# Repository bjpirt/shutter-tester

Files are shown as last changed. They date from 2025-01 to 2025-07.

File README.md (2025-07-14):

# Shutter Tester

A low cost but capable three-point shutter speed tester that runs on ESP32. It uses the PCB design to provide the physical structure of the tester so that all you need to do is solder it together and all of the mechanical design is taken care of.
It runs on ESP32 so is easily updated using the Arduino platform. The project is 100% open source (see the [license file](LICENSE.md) for details).
The UI runs in the browser and communicates with the shutter tester via Bluetooth - you can try out the UI [here](https://bjpirt.github.io/shutter-tester/?demo=true).

## Design

The design of the shutter tester is quite simple; it uses three IS485E / IS486E light sensors with built-in amplifiers to trigger three digital input interrupts on the ESP32 MCU. I wanted to keep the front side of the PCB clear to avoid it ever scratching the camera body so have opted for using surface mount components. I've used quite large packages for these so that they can be more easily hand soldered. The ESP32 uses an "ESP32 C3 Super Mini" module which is very small, can be surface mounted and has USB C built-in which can be used to power the whole board. I've kept the PCB size down to 50mm so that you can take advantage of low cost PCB fabrication. There are silk-screen markings to help position the tester over the camera shutter and three large holes to help see the edges from behind. It should either be taped in place or held with an elastic band.

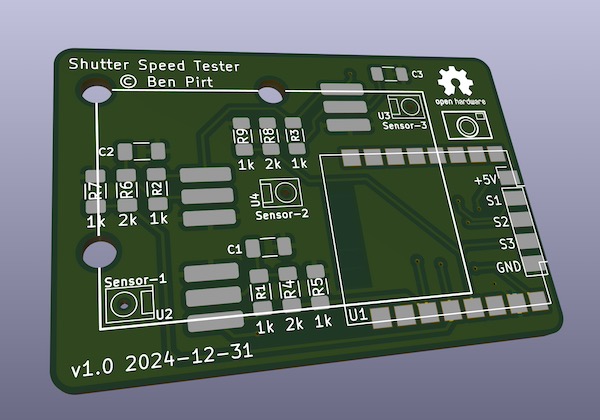
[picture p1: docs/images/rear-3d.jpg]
The shutter tester PCB rear in 3D

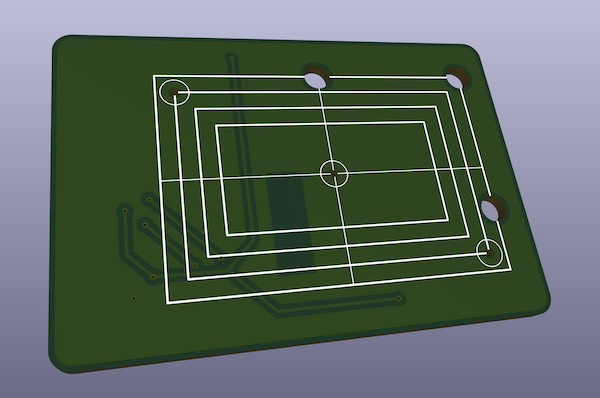
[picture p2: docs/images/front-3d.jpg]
The shutter tester PCB front in 3D

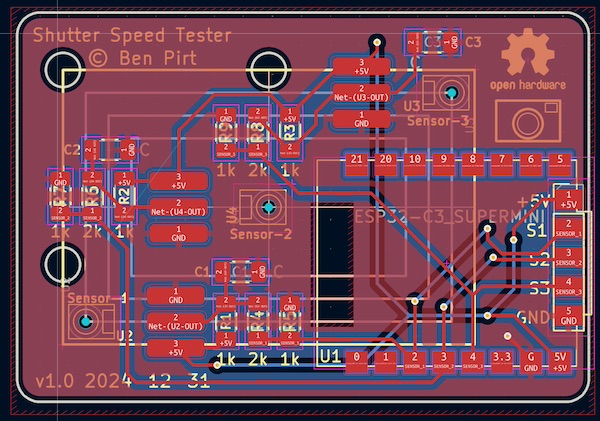
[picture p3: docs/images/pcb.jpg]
The shutter tester PCB


The sensor has a Bluetooth connection and you can connect this to Chrome to use quite a capable web interface so you can get a lot of detail on the calibration. You can try out the UI [here](https://bjpirt.github.io/shutter-tester/?demo=true)

## Bill of materials

The BoM is quite low cost and relatively minimal:

- 1 x ESP32 C3 Super Mini module
- 3 x IS485E light sensor
- 6 x 1k 1206 SMD Resistor
- 3 x 2k 1206 SMD Resistor
- 3 x 0.01uF 1206 SMD Capacitor

## Assembly

The main thing to take care over during assembly is to ensure the lens of the light sensor aligns to the small hole in the PCB that allows the light through. The three legs of the sensor should be bent down slightly so that they can solder onto the three pads on the PCB.

The capacitors and resistors can be easily hand soldered (a finer soldering iron tip helps here) by applying solder to one of the pads on the PCB, using tweezers, solder one end of the component to the soldered pad on the PCB, then solder the other end once it is held in place. If you're experienced in surface mounting you could always use solder paste, but it's pretty straightforward without this. There are markings on the board for which component goes where (C1, C2 and C3 for the capacitors, Resistor values are marked 1k and 2k). The capacitors are optional and may be removed in a future iteration.

It's best to test the ESP32 module before soldering to ensure it's working fine. Program this using the sketch included and make sure it is outputting "Ready to measure" on the serial console (running at 921600 baud).

It's a good idea to place some black insulation tape over the back of the sensors otherwise stray light can cause false readings.

## Usage

Attach the shutter tester behind the shutter of the camera (I normally use 2 - 3 small blobs of Blu-Tak which works well). You can use the three larger holes in the tester to align with the edges of the shutter aperture. Open the shutter once you've this so you can check it's properly positioned by setting the shutter to "Bulb" and opening it. Remove the lens (if possible) and place a strong, even light at the front of the camera. You can use a full size bulb for this so long as it is the type that has a white diffuser bulb, not clear. Basically you want to ensure that light can pass directly through the three holes to reach the sensors, not at an angle. I've also had good results with a small USB powered LED panel.

### Using Bluetooth

There is a user interface that connects to the ESP32 from a Chrome web browser directly and lets you analyse all of the measurements quite easily.

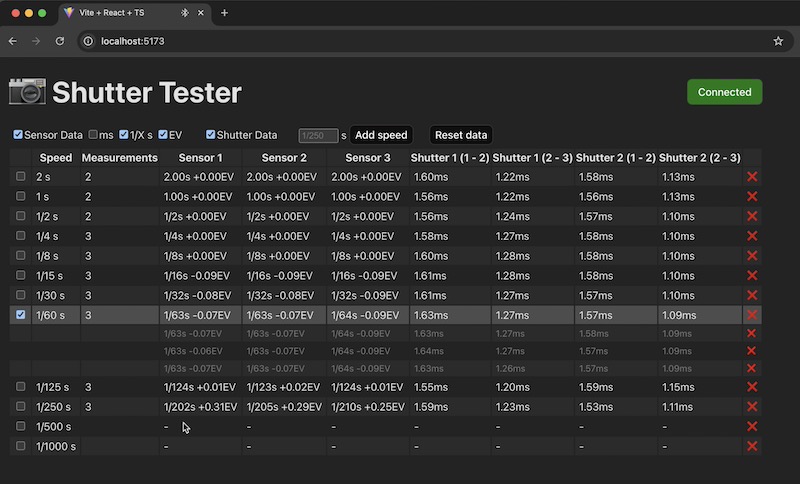
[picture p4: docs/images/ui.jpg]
The Bluetooth user interface


You can easily use the [latest version](https://bjpirt.github.io/shutter-tester/). You should then be able to click the `Connect` button and pair with your shutter tester using Bluetooth. Select the speed you want to test, set up the light and fire the shutter. The new reading should appear in the table.

If you want to just try out the UI without a tester, you can use [this link](https://bjpirt.github.io/shutter-tester/?demo=true) and the "Test" button will simulate a shutter being fired. From a privacy perspective, the UI runs entirely in your browser and nothing goes over the internet.

If you want to run this locally you can do the following:

- Install Node.js (v22)
- Open a terminal in the `ui` folder of this repository
- run `npm install`
- run `npm run dev`
- Go to the URL printed in your terminal ([http://localhost:5173/](http://localhost:5173/))

### Using serial

Open a serial terminal to the ESP32 (this is built in to the Arduino IDE). You'll need to connect at 921600 baud.

Fire the shutter and it will print out the timings to the serial console. There are two sets of timings:

- The time taken for each shutter to travel across the frame - it's important to try and get both shutters moving at around the same speed
- The time each sensor was exposed for in microseconds, milliseconds and fractions of a second

```
Ready to measure

Shutter timing
Shutter 1: 1-2: 16582 uS || 2-3: 12632 uS
Shutter 2: 1-2: 23756 uS || 2-3: 18462 uS

Exposure timing
Sensor 1: 4346 uS || 4.3 mS || 1 / 228
Sensor 2: 5028 uS || 5.0 mS || 1 / 198
Sensor 3: 5528 uS || 5.5 mS || 1 / 182
```

In this example, the time taken for the first shutter to travel between the first and second (centre) sensors was 16582 microseconds and 12632 microseconds between the second (centre) and third sensor. You can see that in this example the second shutter is slow and would need adjusting.

Looking at the exposure time at each sensor, you can see the timings would need adjusting to give a good even exposure. First you would adjust the shutter timings to try and get them similar and then adjust both shutter tensioners to get the exposure time to match the expected (in this case it should have been 1/250 S)

# To Do

- [ ] Calculate variations across shutter and whether they are within tolerances
- [ ] Add graph visualisation of shutter speeds
- [ ] Generate report from three point test
- [x] Enable detailed measurements to be shown / hidden in three point mode
- [x] Deploy to GitHub pages using GitHub actions
- [x] Automatically work out vertical or horizontal shutter
- [x] Display full shutter timing
- [x] Separate shutter timing mode
- [x] Single shot mode (only show last shot timing) - useful for initial tuning
- [x] Compensation for sensor width

## Future

- [ ] Add persistence in the browser to enable common presets to be stored - e.g. camera types with speeds
- [ ] Enable different "runs" to be stored and compared so you can see progression when adjusting
- [ ] Add exposure measurement with light to frequency sensor
- [ ] Investigate reflective measurement from front of camera for e.g. Barnack Leicas
- [ ] Investigate using an analog photodiode instead of a binary sensor

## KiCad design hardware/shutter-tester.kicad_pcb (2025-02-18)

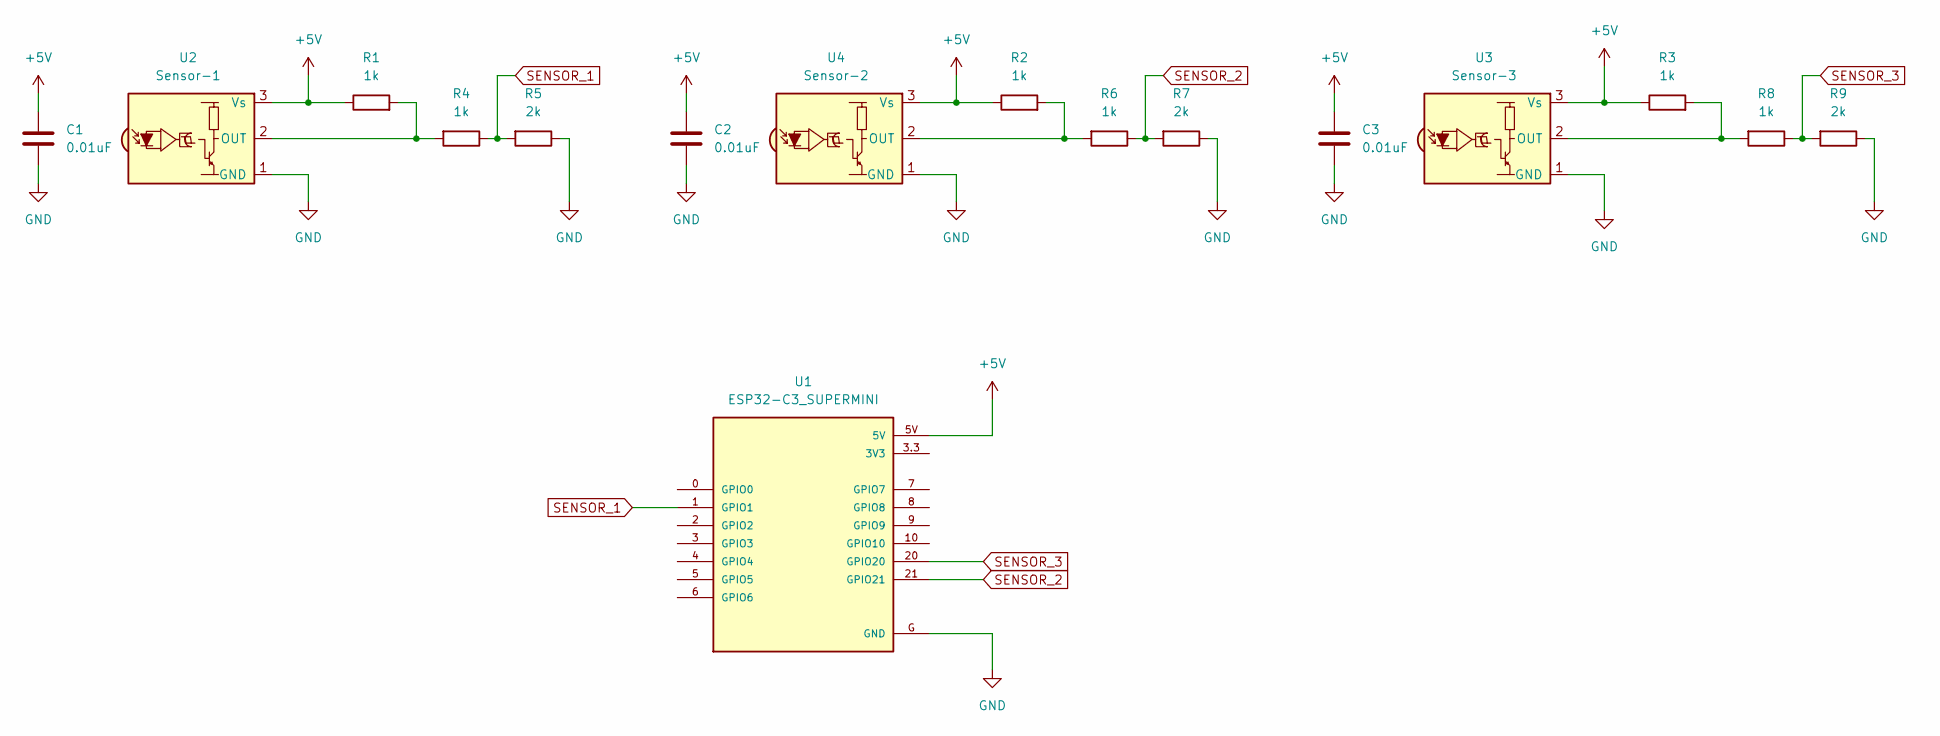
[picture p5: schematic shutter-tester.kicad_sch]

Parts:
C1, C2, C3: 0.01uF; C_1206_3216Metric_Pad1.33x1.80mm_HandSolder
R1, R2, R3, R4, R6, R8: 1k; R_1206_3216Metric_Pad1.30x1.75mm_HandSolder
R5, R7, R9: 2k; R_1206_3216Metric_Pad1.30x1.75mm_HandSolder
U1: ESP32-C3_SUPERMINI; MODULE_ESP32-C3_SUPERMINI_SMT
U2: Sensor-1; Sharp_IS485_Flat_Mount
U3: Sensor-3; Sharp_IS485_Flat_Mount
U4: Sensor-2; Sharp_IS485_Flat_Mount

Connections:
+5V: C1.2, C2.1, C3.2, R1.1, R2.1, R3.1, U1.5V, U2.3 (Vs), U3.3 (Vs), U4.3 (Vs)
GND: C1.1, C2.2, C3.1, R5.1, R7.1, R9.1, U1.G (GND), U2.1 (GND), U3.1 (GND), U4.1 (GND)
unnamed: R1.2, R4.2, U2.2 (OUT)
unnamed: R3.2, R8.2, U3.2 (OUT)
unnamed: R2.2, R6.2, U4.2 (OUT)
SENSOR_1: R4.1, R5.2, U1.1 (GPIO1)
SENSOR_2: R6.1, R7.2, U1.21 (GPIO21)
SENSOR_3: R8.1, R9.2, U1.20 (GPIO20)

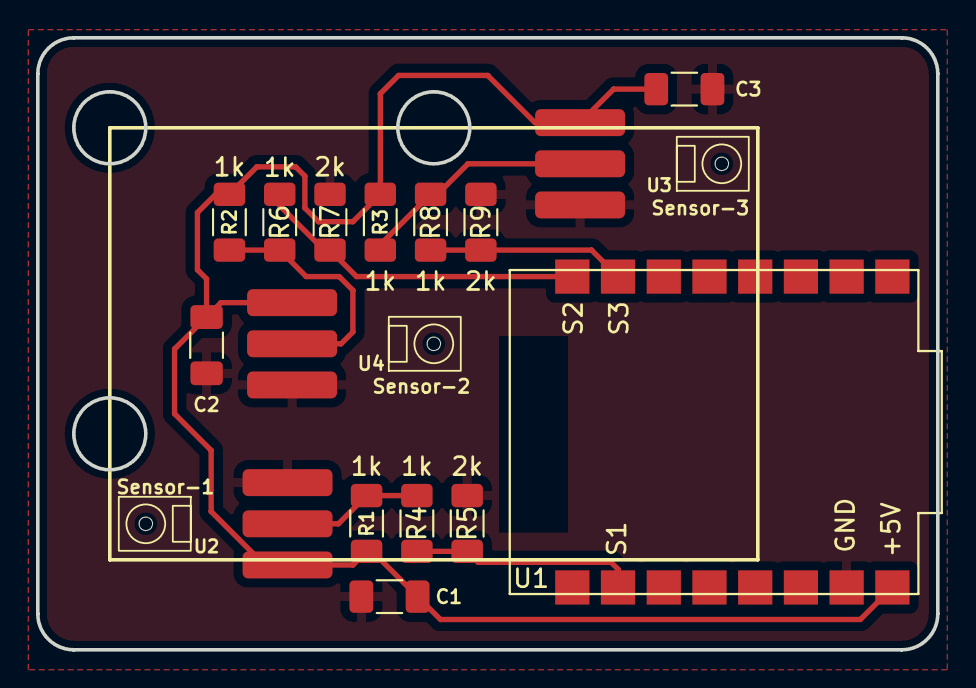
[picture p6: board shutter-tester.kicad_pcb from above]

Board: 2 copper layers, 50.0 x 34.0 mm, 16 parts (0 on the bottom side), 8 nets.

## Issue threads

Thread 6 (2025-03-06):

Seemingly contradictory curtain speed vs exposure

Camacazi, 2025-03-06:
Just wanted to double check that I'm not misunderstanding this correctly in the following screenshot (ignore that outlier entry in the 2nd row).
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

This curtain shutter time appears to imply that the 1st curtain is moving faster than the second (12.79ms vs 13.82 in the 3rd row), but the exposure times across the frame are decreasing, implying the 2nd curtain is running faster.

Am I misinterpreting something? The two seem to be contradicting each other.

Camacazi, 2025-03-06:
Oh okay part of this was my misunderstanding of how the sensors are labelled (1,2,3) vs how the direction of the curtain goes the opposite direction to them (3,2,1).

Closed 2025-03-06.

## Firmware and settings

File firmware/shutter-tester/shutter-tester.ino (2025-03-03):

#define LED 8
#define SENSOR_1 1
#define SENSOR_2 21
#define SENSOR_3 20

#define VERSION "2.2.0"

// #define TEST_BLUETOOTH

#include <BLEDevice.h>
#include <BLEServer.h>
#include <BLEUtils.h>
#include <BLE2902.h>

typedef enum {
  WAIT_FOR_OPEN,
  WAIT_FOR_CLOSE,
  DONE
} sensor_state;

typedef enum {
  THREE_POINT,
  SINGLE_POINT
} sensor_mode;

sensor_state sensor1_state = WAIT_FOR_OPEN;
sensor_state sensor2_state = WAIT_FOR_OPEN;
sensor_state sensor3_state = WAIT_FOR_OPEN;
long sensor1_open_time;
long sensor1_close_time;
long sensor2_open_time;
long sensor2_close_time;
long sensor3_open_time;
long sensor3_close_time;
sensor_mode mode = THREE_POINT;

BLEServer *pServer = NULL;
BLECharacteristic *pSensorCharacteristic = NULL;
BLECharacteristic *pModeCharacteristic = NULL;
bool deviceConnected = false;
bool oldDeviceConnected = false;
char message[128];
long i = 0;

#define SERVICE_UUID "42de79f1-7248-4c9b-9279-96509b8a9f5c"
#define SENSOR_CHARACTERISTIC_UUID "42de79f1-7248-4c9b-9279-96509b8a9f5d"
#define MODE_CHARACTERISTIC_UUID "42de79f1-7248-4c9b-9279-96509b8a9f5e"
#define DEVICE_NAME "ShutterTester"

class MyServerCallbacks : public BLEServerCallbacks {
  void onConnect(BLEServer *pServer) {
    deviceConnected = true;
  };

  void onDisconnect(BLEServer *pServer) {
    deviceConnected = false;
  }
};

class ModeCharacteristicCallbacks : public BLECharacteristicCallbacks {
  void onWrite(BLECharacteristic *pModeCharacteristic) {
    String value = pModeCharacteristic->getValue();
    if (value.length() > 0) {
      int newMode = static_cast<int>(value[0]);
      if (newMode == 1) {
        Serial.print("Setting mode to single point");
        mode = SINGLE_POINT;
      } else if (newMode == 2) {
        Serial.print("Setting mode to three point");
        mode = THREE_POINT;
      }
    }
  }
};

void IRAM_ATTR sensor1_isr() {
  if (!digitalRead(SENSOR_1)) {
    sensor1_open_time = micros();
    sensor1_state = WAIT_FOR_CLOSE;
  } else {
    sensor1_close_time = micros();
    sensor1_state = DONE;
  }
}

void IRAM_ATTR sensor2_isr() {
  if (!digitalRead(SENSOR_2)) {
    sensor2_open_time = micros();
    sensor2_state = WAIT_FOR_CLOSE;
  } else {
    sensor2_close_time = micros();
    sensor2_state = DONE;
  }
}

void IRAM_ATTR sensor3_isr() {
  if (!digitalRead(SENSOR_3)) {
    sensor3_open_time = micros();
    sensor3_state = WAIT_FOR_CLOSE;
  } else {
    sensor3_close_time = micros();
    sensor3_state = DONE;
  }
}

void print_shutter_timing(long t1, long t2, long t3) {
  long s1t1 = t2 - t1;
  long s1t2 = t3 - t2;
  Serial.print(" 1-2: ");
  Serial.print(s1t1);
  Serial.print(" uS || 2-3: ");
  Serial.print(s1t2);
  Serial.println(" uS");
}

void print_exposure_timing(long open_time, long close_time) {
  long interval = close_time - open_time;
  Serial.print(interval);
  Serial.print(" uS  ||  ");

  float milliseconds = interval / 1000.0;

  Serial.print(milliseconds);
  Serial.print(" mS  ||  ");

  float seconds = interval / 1000000.0;
  long inverse = 1 / seconds;

  Serial.print("1 / ");
  Serial.print(inverse);
  Serial.println(" S");
}

void print_three_point_summary(long s1_open_time,
                               long s1_close_time,
                               long s2_open_time,
                               long s2_close_time,
                               long s3_open_time,
                               long s3_close_time) {
  // Print shutter timings
  Serial.println("\r\nShutter timing");
  Serial.print("Shutter 1: ");
  print_shutter_timing(s1_open_time, s2_open_time, s3_open_time);

  Serial.print("Shutter 2: ");
  print_shutter_timing(s1_close_time, s2_close_time, s3_close_time);

  // Print sensor timings
  Serial.println("\r\nExposure timing");
  Serial.print("Sensor 1: ");
  print_exposure_timing(s1_open_time, s1_close_time);
  Serial.print("Sensor 2: ");
  print_exposure_timing(s2_open_time, s2_close_time);
  Serial.print("Sensor 3: ");
  print_exposure_timing(s3_open_time, s3_close_time);
}

void print_single_point_summary(long s2_open_time, long s2_close_time) {
  Serial.println("\r\nExposure timing");
  print_exposure_timing(s2_open_time, s2_close_time);
}

void setupBluetooth() {
  BLEDevice::init(DEVICE_NAME);

  pServer = BLEDevice::createServer();
  pServer->setCallbacks(new MyServerCallbacks());

  // Create the BLE Service
  BLEService *pService = pServer->createService(SERVICE_UUID);

  // Create a BLE Characteristic
  pSensorCharacteristic = pService->createCharacteristic(
    SENSOR_CHARACTERISTIC_UUID,
    BLECharacteristic::PROPERTY_READ | BLECharacteristic::PROPERTY_WRITE | BLECharacteristic::PROPERTY_NOTIFY | BLECharacteristic::PROPERTY_INDICATE);

  // Create the mode Characteristic
  pModeCharacteristic = pService->createCharacteristic(
    MODE_CHARACTERISTIC_UUID,
    BLECharacteristic::PROPERTY_WRITE);

  pModeCharacteristic->setCallbacks(new ModeCharacteristicCallbacks());

  // Create a BLE Descriptor
  pSensorCharacteristic->addDescriptor(new BLE2902());
  pModeCharacteristic->addDescriptor(new BLE2902());

  // Start the service
  pService->start();

  // Start advertising
  BLEAdvertising *pAdvertising = BLEDevice::getAdvertising();
  pAdvertising->addServiceUUID(SERVICE_UUID);
  pAdvertising->setScanResponse(false);
  pAdvertising->setMinPreferred(0x0);
  BLEDevice::startAdvertising();
}

void setup() {
  Serial.begin(115200);
  Serial.println("");
  Serial.println("Ready to measure");
  pinMode(LED, OUTPUT);
  pinMode(SENSOR_1, INPUT);
  pinMode(SENSOR_2, INPUT);
  pinMode(SENSOR_3, INPUT);
  attachInterrupt(SENSOR_1, sensor1_isr, CHANGE);
  attachInterrupt(SENSOR_2, sensor2_isr, CHANGE);
  attachInterrupt(SENSOR_3, sensor3_isr, CHANGE);

  setupBluetooth();
}

bool ready() {
  return (mode == THREE_POINT && sensor1_state == DONE && sensor2_state == DONE && sensor3_state == DONE) || (mode == SINGLE_POINT && sensor2_state == DONE);
}

void three_point_output() {
  if (sensor1_open_time < sensor3_open_time) {
    print_three_point_summary(sensor1_open_time,
                              sensor1_close_time,
                              sensor2_open_time,
                              sensor2_close_time,
                              sensor3_open_time,
                              sensor3_close_time);
  } else {
    print_three_point_summary(sensor3_open_time,
                              sensor3_close_time,
                              sensor2_open_time,
                              sensor2_close_time,
                              sensor1_open_time,
                              sensor1_close_time);
  }

  if (deviceConnected) {
    long minTime = min(sensor1_open_time, sensor3_open_time);
    sprintf(message, "{\"type\":\"three_point\",\"sensor1\":{\"open\":%ld,\"close\":%ld},\"sensor2\":{\"open\":%ld,\"close\":%ld},\"sensor3\":{\"open\":%ld,\"close\":%ld}}",
            sensor1_open_time - minTime,
            sensor1_close_time - minTime,
            sensor2_open_time - minTime,
            sensor2_close_time - minTime,
            sensor3_open_time - minTime,
            sensor3_close_time - minTime);

    pSensorCharacteristic->setValue(message);
    pSensorCharacteristic->notify();
  }
}

char *getMode() {
  if (mode == THREE_POINT) {
    return "three_point";
  } else if (mode == SINGLE_POINT) {
    return "single_point";
  }
}

void metadata_output() {
  if (deviceConnected) {
    long minTime = min(sensor1_open_time, sensor3_open_time);
    sprintf(message, "{\"type\":\"metadata\",\"mode\":\"%s\",\"version\":%s}", getMode(), VERSION);

    pSensorCharacteristic->setValue(message);
    pSensorCharacteristic->notify();
  }
}

void single_point_output() {
  print_single_point_summary(sensor2_open_time, sensor2_close_time);

  if (deviceConnected) {
    long minTime = min(sensor1_open_time, sensor3_open_time);
    sprintf(message, "{\"type\":\"single_point\",\"sensor2\":%ld}", sensor2_close_time - sensor2_open_time);

    pSensorCharacteristic->setValue(message);
    pSensorCharacteristic->notify();
  }
}

void loop() {
  if ((mode == THREE_POINT && (sensor1_state == sensor2_state == sensor3_state == WAIT_FOR_CLOSE)) || (mode == SINGLE_POINT && sensor2_state == WAIT_FOR_CLOSE)) {
    digitalWrite(LED, LOW);
  }else{
    digitalWrite(LED, HIGH);
  }

  if (ready()) {
    digitalWrite(LED, LOW);

    sensor1_state = WAIT_FOR_OPEN;
    sensor2_state = WAIT_FOR_OPEN;
    sensor3_state = WAIT_FOR_OPEN;

    if (mode == THREE_POINT) {
      three_point_output();
    } else if (mode == SINGLE_POINT) {
      single_point_output();
    }
  }

  // disconnecting
  if (!deviceConnected && oldDeviceConnected) {
    Serial.println("Device disconnected.");
    delay(1000);                  // give the bluetooth stack the chance to get things ready
    pServer->startAdvertising();  // restart advertising
    Serial.println("Start advertising");
    oldDeviceConnected = deviceConnected;
  }

  // connecting
  if (deviceConnected && !oldDeviceConnected) {
    oldDeviceConnected = deviceConnected;
    Serial.println("Device Connected");
    metadata_output();
  }

#ifdef TEST_BLUETOOTH
  if (millis() % 5000 == 0) {
    i++;
    if (deviceConnected) {
      Serial.println("Sending measurements");
      sensor1_open_time = 0 + i;
      sensor1_close_time = 11111 + i;
      sensor2_open_time = 33333 + i;
      sensor2_close_time = 44444 + i;
      sensor3_open_time = 77777 + i;
      sensor3_close_time = 88888 + i;

      sensor1_state = DONE;
      sensor2_state = DONE;
      sensor3_state = DONE;
    }
  }
#endif
}

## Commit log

2025-01-24 Initial commit of project
    [shutter-tester.kicad_pcb, shutter-tester.kicad_sch]
2025-01-28 v2.0 of the hardware
    [shutter-tester.kicad_pcb, shutter-tester.kicad_sch]
2025-01-31 Don't use GPIO 0 for sensor input
    [shutter-tester.kicad_pcb, shutter-tester.kicad_sch]
2025-02-18 v2.1 of the PCB
    [shutter-tester.kicad_pcb]
2025-03-03 Enable the mode to be set on the sensor via Bluetooth
2025-03-07 Add initial implementation of sensor width compensation
2025-03-22 Wire up the different pages with an internal message bus

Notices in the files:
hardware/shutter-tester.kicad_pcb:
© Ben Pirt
